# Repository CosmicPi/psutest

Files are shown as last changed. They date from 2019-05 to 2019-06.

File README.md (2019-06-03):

# psutest
Power supply test for Cockcroft Walton converter
Hardware tested and working as expected with a Digital Multi-Meter, need to check it with a scope. It is designed to work with the Ketek [PM3325 SiPM](https://www.ketek.net/wp-content/uploads/2018/12/KETEK-PM3325-WB-D0-Datasheet.pdf) module. In the meantime check out the LTSpice model!
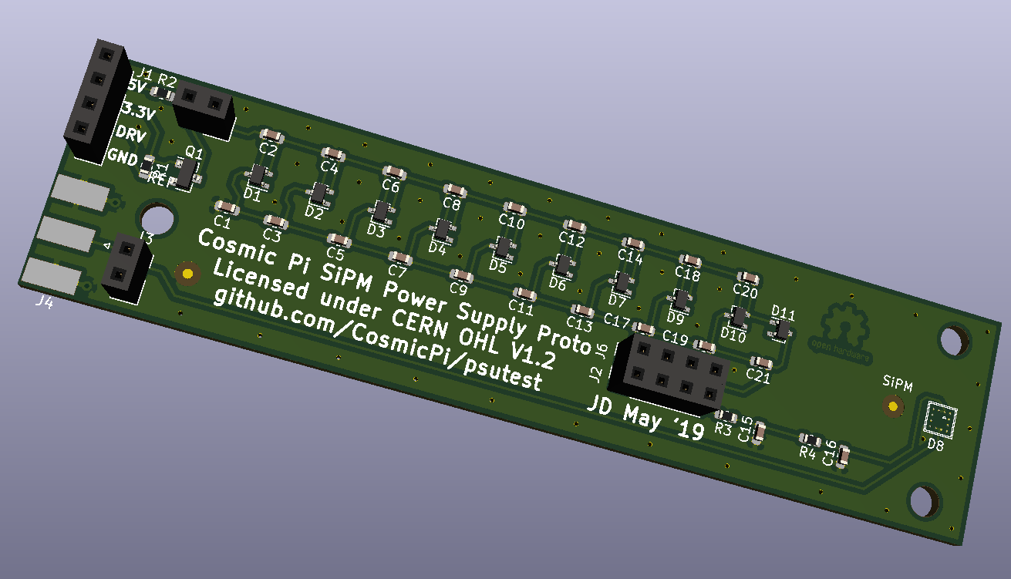
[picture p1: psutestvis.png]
Render of the board

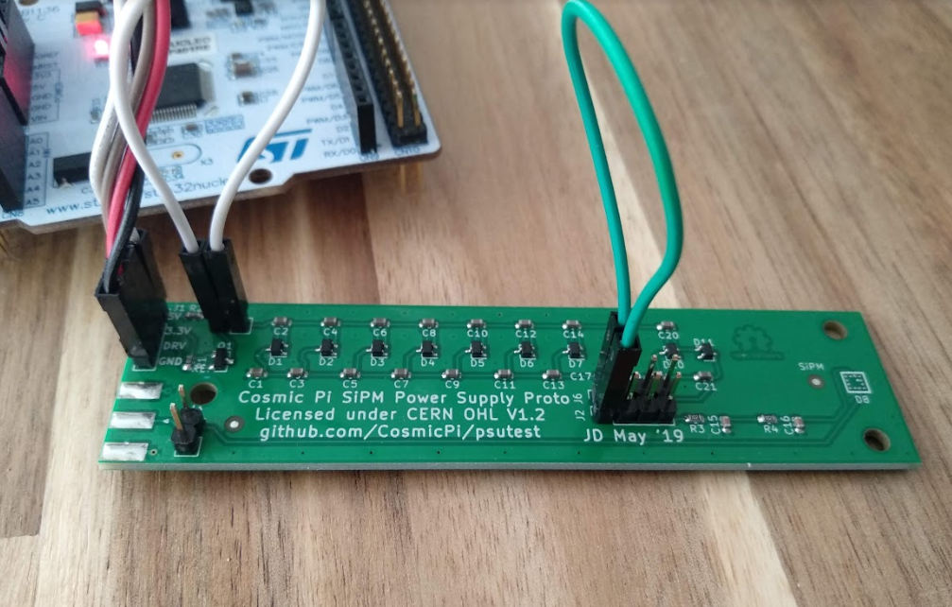
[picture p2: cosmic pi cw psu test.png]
The actual hardware, hooked up for test


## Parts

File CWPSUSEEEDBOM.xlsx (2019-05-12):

Designator | Manufacturer Part Number or Seeed SKU | Qty | Link
J6,J2,J1 | P125-1104A0BS116A1 | 3 | https://www.seeedstudio.com/opl.html
J5,J3 | P125-1102A0BS116A1 | 2 | https://www.seeedstudio.com/opl.html
D11,D10,D9,D7,D6,D5,D4,D3,D2,D1 | BAT54SW-7-F | 10 | https://www.seeedstudio.com/opl.html
C21,C20,C19,C18,C17,C14,C13,C12,C11,C10,C9,C8,C7,C6,C5,C4,C3,C2,C1 | CC0603KRX5R6BB106 | 19 | https://www.seeedstudio.com/opl.html
R4,R3 | RC0603JR-071KL | 2 | https://www.seeedstudio.com/opl.html
R2 | RC0603JR-07180RL | 1 | https://www.seeedstudio.com/opl.html
R1 | RC0603JR-0710KL | 1 | https://www.seeedstudio.com/opl.html
C16,C15 | CL10A105KB8NNNC | 2 | https://www.seeedstudio.com/opl.html
Q1 | BSS123-7-F | 1 | https://www.seeedstudio.com/opl.html
JU1, JU2 | 320190003 | 2 | https://statics3.seeedstudio.com/images/opl/datasheet/3460440P1.pdf

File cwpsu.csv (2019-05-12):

Id | Designator | Package | Quantity | Designation | Supplier and ref
1 | REF**,REF**,REF** | MountingHole_3.2mm_M3_ISO7380 | 3 | MountingHole_3.2mm_M3_ISO7380
2 | REF** | OSHW-Logo2_7.3x6mm_Copper | 1 | OSHW-Logo2_7.3x6mm_Copper
3 | SiPM,Input | Fiducial_1mm_Dia_2.54mm_Outer_CopperTop | 2 | Fiducial_1mm_Dia_2.54mm_Outer_CopperTop
4 | D8 | Ketek_PM3325-WB | 1 | D_SiPM
5 | J6,J2,J1 | PinSocket_1x04_P2.54mm_Vertical | 3 | Conn_01x04_Male
6 | J5,J3 | PinSocket_1x02_P2.54mm_Vertical | 2 | Conn_01x02_Male
7 | D11,D10,D9,D7,D6,D5,D4,D3,D2,D1 | SOT-323_SC-70 | 10 | BAT54SW
8 | C21,C20,C19,C18,C17,C14,C13,C12,C11,C10,C9,C8,C7,C6,C5,C4,C3,C2,C1 | C_0603_1608Metric | 19 | 10u
9 | J4 | SMA_Molex_73251-1153_EdgeMount_Horizontal | 1 | Conn_Coaxial
10 | R4,R3 | R_0603_1608Metric | 2 | 1k
11 | R2 | R_0603_1608Metric | 1 | 180
12 | R1 | R_0603_1608Metric | 1 | 10k
13 | C16,C15 | C_0603_1608Metric | 2 | 1u
14 | Q1 | SOT-23 | 1 | BSS123

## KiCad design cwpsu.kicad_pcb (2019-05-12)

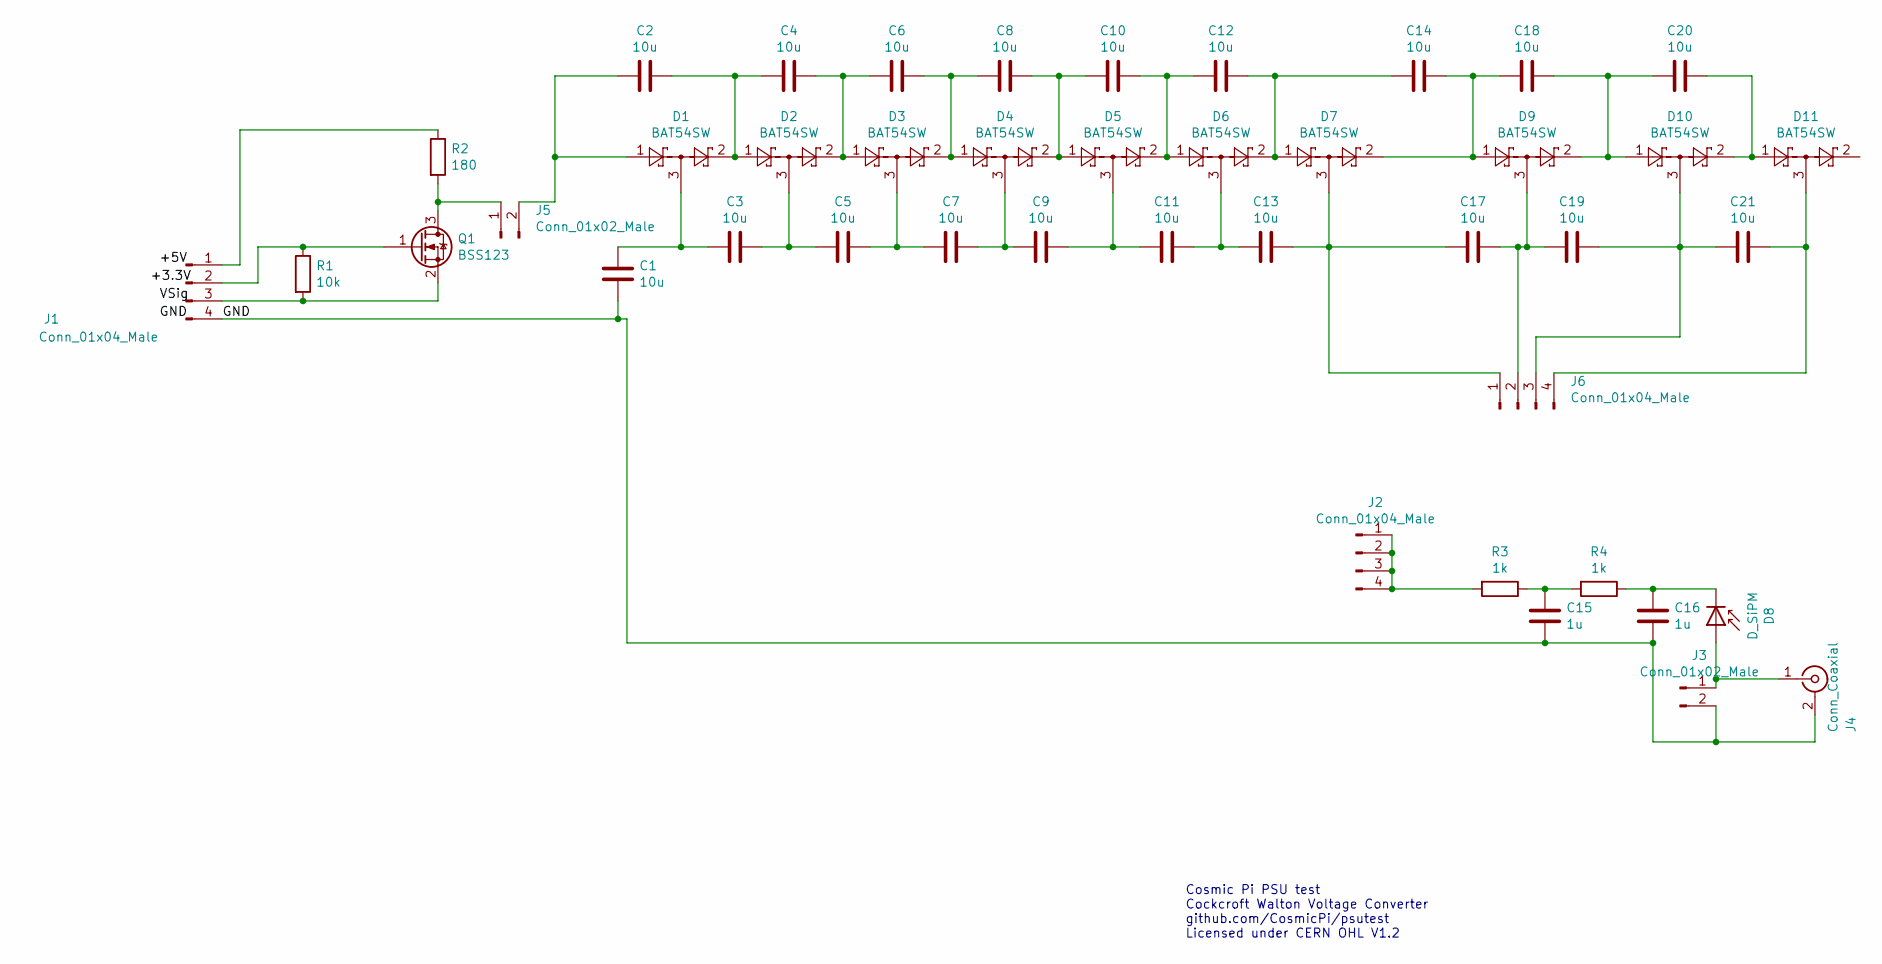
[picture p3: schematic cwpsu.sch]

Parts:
C1, C2, C3, C4, C5, C6, C7, C8, C9, C10, C11, C12, C13, C14, C17, C18, C19, C20, C21: 10u; C_0603_1608Metric
C15, C16: 1u; C_0603_1608Metric
D1, D2, D3, D4, D5, D6, D7, D9, D10, D11: BAT54SW; SOT-323_SC-70
D8: D_SiPM; Ketek_PM3325-WB
J1, J2, J6: Conn_01x04_Male; PinSocket_1x04_P2.54mm_Vertical
J3, J5: Conn_01x02_Male; PinSocket_1x02_P2.54mm_Vertical
J4: Conn_Coaxial; SMA_Molex_73251-1153_EdgeMount_Horizontal
Q1: BSS123; SOT-23
R1: 10k; R_0603_1608Metric
R2: 180; R_0603_1608Metric
R3, R4: 1k; R_0603_1608Metric

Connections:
/GND: C1.1, C15.1, C16.1, J1.4, J3.2, J4.2 (Ext)
unnamed: C1.2, C3.2, D1.3
unnamed: C2.1, C4.2, D1.2, D2.1
unnamed: C2.2, D1.1, J5.2
unnamed: C3.1, C5.2, D2.3
unnamed: C4.1, C6.2, D2.2, D3.1
unnamed: C5.1, C7.2, D3.3
unnamed: C6.1, C8.2, D3.2, D4.1
unnamed: C7.1, C9.2, D4.3
unnamed: C10.1, C12.2, D5.2, D6.1
unnamed: C8.1, C10.2, D4.2, D5.1
unnamed: C11.1, C13.2, D6.3
unnamed: C9.1, C11.2, D5.3
unnamed: C12.1, C14.2, D6.2, D7.1
unnamed: C13.1, C17.2, D7.3, J6.1
unnamed: C14.1, C18.2, D7.2, D9.1
unnamed: C15.2, R3.1, R4.2
unnamed: C16.2, D8.1 (K), R4.1
unnamed: C17.1, C19.2, D9.3, J6.2
unnamed: C18.1, C20.2, D9.2, D10.1
unnamed: C19.1, C21.2, D10.3, J6.3
unnamed: C20.1, D10.2, D11.1
unnamed: C21.1, D11.3, J6.4
unnamed: D8.2 (A), J3.1, J4.1 (In)
unnamed: J1.1, R2.1
unnamed: J1.2, Q1.1 (G), R1.1
unnamed: J1.3, Q1.2 (S), R1.2
unnamed: J2.1, J2.2, J2.3, J2.4, R3.2
unnamed: J5.1, Q1.3 (D), R2.2

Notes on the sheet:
Cosmic Pi PSU test Cockcroft Walton Voltage Converter github.com/CosmicPi/psutest Licensed under CERN OHL V1.2

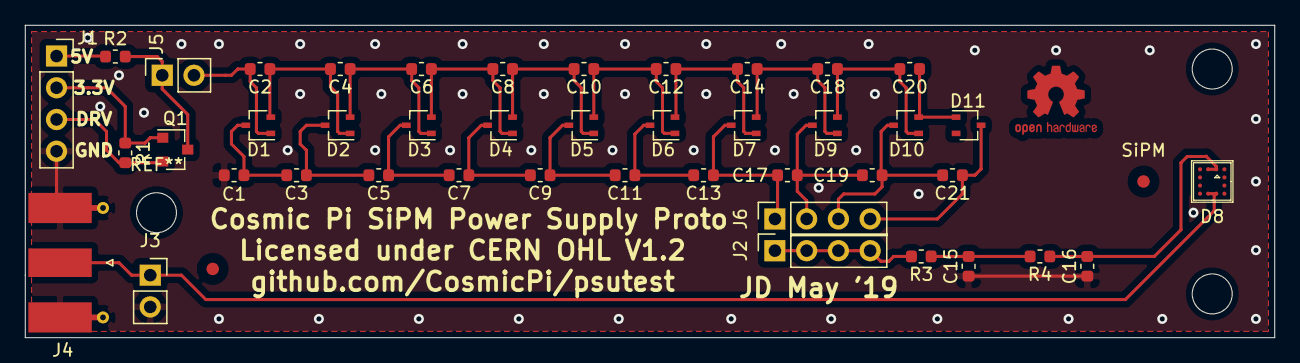
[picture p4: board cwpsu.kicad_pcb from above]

Board: 2 copper layers, 100.0 x 25.0 mm, 45 parts (0 on the bottom side), 29 nets.

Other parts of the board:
Input: Fiducial_1mm_Dia_2.54mm_Outer_CopperTop
SiPM: Fiducial_1mm_Dia_2.54mm_Outer_CopperTop

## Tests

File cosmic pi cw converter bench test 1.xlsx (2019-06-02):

Cosmic Pi PSU - sample evaluation - with multimeter and STM32F401RE nucleo demo board.
Ripple not measured, slight drop in voltage when DMM connected, SiPM not mounted. First measurement position (i.e. lowest voltage multiplication).
 | Freq | Time | Duty | Output
Input | 100 | 0.01 | 0.5 | 27.92 | V
 | 1000 | 0.001 | 0.5 | 28.83 | V
 | 10000 | 0.0001 | 0.5 | 28.86
 | 100000 | 1e-05 | 0.95 | 28.76
 | 100000 | 1e-05 | 0.7 | 28.89
 | 100000 | 1e-05 | 0.6 | 28.9
 | 100000 | 1e-05 | 0.5 | 28.86
 | 100000 | 1e-05 | 0.4 | 28.8
 | 100000 | 1e-05 | 0.35 | 28.79
 | 100000 | 1e-05 | 0.3 | 28.75
 | 100000 | 1e-05 | 0.25 | 28.68
 | 100000 | 1e-05 | 0.2 | 28.66
 | 100000 | 1e-05 | 0.15 | 28.39
 | 100000 | 1e-05 | 0.1 | 28.38
 | 100000 | 1e-05 | 0.07 | x

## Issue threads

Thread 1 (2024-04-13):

where is the  LTSpice model of  diode of BAS16?

zzsczz, 2024-04-13:
bas16gw.lib is missing

pingud98, 2024-04-15:
Thanks for the feedback, I'm afraid we stopped looking at a CW based converter as it was hard to get the ripple out, and the SiPM we were targetting has been discontinued. We are building a new small run of boards for testing using the MAX5026 IC. You can find details of the new power supply circuit we are using here: https://pdfserv.maximintegrated.com/en/an/AN895.pdf

As for the missing file, you can find it here: https://assets.nexperia.com/documents/spice-model/BAS16GW.txt but it will need to be re-imported into your spice environment, with the method depending upon your OS platform.

Closed 2024-04-15.

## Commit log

2019-05-12 Kicad files upload
    [cwpsu.csv, cwpsu.kicad_pcb, cwpsu.sch]
2019-05-12 Spice simulation file
    Target voltage is about 27 volts.
2019-06-02 Added photo of the hardware and first test results
    [cosmic pi cw converter bench test 1.xlsx]
